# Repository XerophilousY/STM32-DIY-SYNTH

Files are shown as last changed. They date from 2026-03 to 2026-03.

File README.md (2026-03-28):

基于STM32F103C8T6温湿度计
---
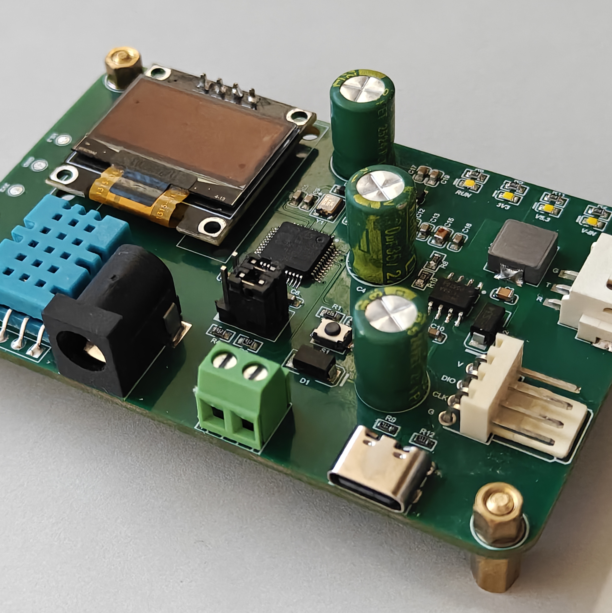
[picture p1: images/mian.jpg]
mian


系统提供多种电源输入方式，包括 Type-C 接口、3.81 mm 间距接线端子以及 DC005（5.5 mm × 2.5 mm）电源插座，以适应不同应用场景的供电需求。外部输入电压为 DC 12V。

电源管理部分采用分级降压方案：首先通过 TPS530 开关型 DC-DC 降压转换器（非线性）将输入电压降至 5V；随后由 TPS73033 或 RT9013 低压差线性稳压器（LDO）进一步稳压至 3.3V，为系统主控 MCU 及相关外设（包括传感器模块与 OLED 显示模块）提供稳定可靠的工作电源。

此外，系统设计预留标准下载接口及串口通信接口，可用于固件烧录、在线调试及数据通信，提升系统开发与维护的便利性。

1.***硬件组件***

主控：STM32F103C8T6 主频8MhZ

传感器：DHT11 单总线通信

显示方式：0.96寸OLED IIC通信

2.***开发工具***

Keil MDK 

Altium designer2020

3.***PCB版本迭代记录***

V0.0：采用的正反面设计，正面芯片，反面OLED,设计不美观，VSS和VDD连接相反

V1.0:晶振网络未连接到3.3v网络上，晶振不启振，打印出的时钟频率不对，软件倍频不生效

V2.0：使用AMS1117降压，输入12V降压至3.3V,压降太高，发热严重，电压不稳定，导致STM32死机，需要手动复位，在软件中加入看门狗后导致间隔性重启

V3.0:采用TPS5430降压至5V，后进入TPS73033降压至3.3v,没有5V输出，也没有3.3v,排查发现TPS73033输入和输出网络不一样，*导致无法形成回路*，因此没有3.3v输出

V4.0：采用四层板子设计，TPS5430用平面分割，但走线凌乱

V5.0：更改部分原件封装，删除0欧电阻作为隔离，每个部分的电源形成了回路，电源稳定

V6.0：锂电池供电版本,未单独区分

V7.0：当前版本

开发与贡献
--
该版本还有很多问题，如未大面积铺铜、集成度不高、欢迎通过以下方式参与贡献

-优化布局、走线

-优化选型，使其体积更轻盈小巧

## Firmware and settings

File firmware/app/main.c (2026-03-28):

//////////////////////////////////////////////////////////////////////////////////
//本程序只供学习使用，未经作者许可，不得用于其它任何用途
//
//  文 件 名   : main.c
//  版 本 号   : v2.0
//  作    者   : YANG HAO JI
//  生成日期   : 2018-10-31
//  最近修改   :
//  功能描述   : OLED I2C接口演示例程(STM32F103系列)
//              说明:
//              ----------------------------------------------------------------
//              GND  电源地
//              VCC  3.3v电源
//              D0   PA0（SCL）
//              D1   PA1（SDA）
//              RES  PA2（SPI模块改成IIC模块需要接此引脚，IIC模块用户请忽略）
//              ----------------------------------------------------------------
// 修改历史   :
// 日    期   :
// 修改内容   : 创建文件
//版权所有，盗版必究。
//All rights reserved
//******************************************************************************/
#include "board.h"
#include "sys.h"
#include "oled.h"
#include "bmp.h"
#include "dht11.h"
#include "stdio.h"
#include "bsp_uart.h"
#include "led.h"
#include "iwdg.h"

int main(void)
{
  DHT11_GPIO_Init();
  board_init();
  OLED_Init();
	LED_Init();
  OLED_ColorTurn(0);//0正常显示，1 反色显示
  OLED_DisplayTurn(0);//0正常显示 1 屏幕翻转显示
  uart1_init(115200U);

	
		IWDG_Feed();//喂狗
		Flag_IWDG_Feed=0;//停止喂狗，准备复位
  while(1)
    {
		
      OLED_Refresh();
      DHT11_Read_Data();

	                 	//表头
						OLED_ShowChinese(0, 0, 0, 16, 1);							   //温
						OLED_ShowChinese(25, 0, 1, 16, 1);							 //湿
						OLED_ShowChinese(50, 0, 2, 16, 1);							 //度
						OLED_ShowChinese(75, 0, 3, 16, 1);							 //检
						OLED_ShowChinese(100, 0, 4, 16, 1);							 //测
			
			
			
			OLED_ShowChinese(0, 25, 0, 16, 1);							 //温
      OLED_ShowChinese(25, 25, 2, 16, 1);							//度
			OLED_ShowString(50,25,":",16,1);
			
      OLED_ShowNum(65, 25, Get_temperature(), 2, 16, 0);      //获取温度值
			OLED_ShowChinese(85,25,5,16,1);												 //温度单位
			
			
			
			
			
			OLED_ShowChinese(0, 45, 1, 16, 1);							//湿
    	OLED_ShowChinese(25, 45, 2, 16, 1);				     //度
			OLED_ShowString(50,45,":",16,1);
			
      OLED_ShowNum(65, 45, Get_humidity(), 2, 16, 0);      //获取湿度值
			OLED_ShowString(90,45,"%",16,1);								   //湿度单位
			
			
			LED_RUN=LED_ON;
      delay_ms(500);
		
		LED_RUN=LED_OFF;
     

    }
}

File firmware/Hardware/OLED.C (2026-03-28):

#include "oled.h"
#include "stdlib.h"
#include "OLED_Font.h"
#include "board.h"

u8 OLED_GRAM[144][8];

//反显函数
void OLED_ColorTurn(u8 i)
{
	if(i==0)
		{
			OLED_WR_Byte(0xA6,OLED_CMD);//正常显示
		}
	if(i==1)
		{
			OLED_WR_Byte(0xA7,OLED_CMD);//反色显示
		}
}

//屏幕旋转180度
void OLED_DisplayTurn(u8 i)
{
	if(i==0)
		{
			OLED_WR_Byte(0xC8,OLED_CMD);//正常显示
			OLED_WR_Byte(0xA1,OLED_CMD);
		}
	if(i==1)
		{
			OLED_WR_Byte(0xC0,OLED_CMD);//反转显示
			OLED_WR_Byte(0xA0,OLED_CMD);
		}
}

//延时
void IIC_delay(void)
{
	u8 t=3;
	while(t--);
}

//起始信号
void I2C_Start(void)
{
	OLED_SDA_Set();
	OLED_SCL_Set();
	IIC_delay();
	OLED_SDA_Clr();
	IIC_delay();
	OLED_SCL_Clr();
	IIC_delay();
}

//结束信号
void I2C_Stop(void)
{
	OLED_SDA_Clr();
	OLED_SCL_Set();
	IIC_delay();
	OLED_SDA_Set();
}

//等待信号响应
void I2C_WaitAck(void) //测数据信号的电平
{
	OLED_SDA_Set();
	IIC_delay();
	OLED_SCL_Set();
	IIC_delay();
	OLED_SCL_Clr();
	IIC_delay();
}

//写入一个字节
void Send_Byte(u8 dat)
{
	u8 i;
	for(i=0;i<8;i++)
	{
		if(dat&0x80)//将dat的8位从最高位依次写入
		{
			OLED_SDA_Set();
    }
		else
		{
			OLED_SDA_Clr();
    }
		IIC_delay();
		OLED_SCL_Set();
		IIC_delay();
		OLED_SCL_Clr();//将时钟信号设置为低电平
		dat<<=1;
  }
}

//发送一个字节
//mode:数据/命令标志 0,表示命令;1,表示数据;
void OLED_WR_Byte(u8 dat,u8 mode)
{
	I2C_Start();
	Send_Byte(0x78);
	I2C_WaitAck();
	if(mode){Send_Byte(0x40);}
  else{Send_Byte(0x00);}
	I2C_WaitAck();
	Send_Byte(dat);
	I2C_WaitAck();
	I2C_Stop();
}

//开启OLED显示 
void OLED_DisPlay_On(void)
{
	OLED_WR_Byte(0x8D,OLED_CMD);//电荷泵使能
	OLED_WR_Byte(0x14,OLED_CMD);//开启电荷泵
	OLED_WR_Byte(0xAF,OLED_CMD);//点亮屏幕
}

//关闭OLED显示 
void OLED_DisPlay_Off(void)
{
	OLED_WR_Byte(0x8D,OLED_CMD);//电荷泵使能
	OLED_WR_Byte(0x10,OLED_CMD);//关闭电荷泵
	OLED_WR_Byte(0xAE,OLED_CMD);//关闭屏幕
}

//更新显存到OLED	
void OLED_Refresh(void)
{
	u8 i,n;
	for(i=0;i<8;i++)
	{
		OLED_WR_Byte(0xb0+i,OLED_CMD); //设置行起始地址
		OLED_WR_Byte(0x00,OLED_CMD);   //设置低列起始地址
		OLED_WR_Byte(0x10,OLED_CMD);   //设置高列起始地址
		I2C_Start();
		Send_Byte(0x78);
		I2C_WaitAck();
		Send_Byte(0x40);
		I2C_WaitAck();
		for(n=0;n<128;n++)
		{
			Send_Byte(OLED_GRAM[n][i]);
			I2C_WaitAck();
		}
		I2C_Stop();
  }
}
//清屏函数
void OLED_Clear(void)
{
	u8 i,n;
	for(i=0;i<8;i++)
	{
	   for(n=0;n<128;n++)
			{
			 OLED_GRAM[n][i]=0;//清除所有数据
			}
  }
	OLED_Refresh();//更新显示
}

//画点 
//x:0~127
//y:0~63
//t:1 填充 0,清空	
void OLED_DrawPoint(u8 x,u8 y,u8 t)
{
	u8 i,m,n;
	i=y/8;
	m=y%8;
	n=1<<m;
	if(t){OLED_GRAM[x][i]|=n;}
	else
	{
		OLED_GRAM[x][i]=~OLED_GRAM[x][i];
		OLED_GRAM[x][i]|=n;
		OLED_GRAM[x][i]=~OLED_GRAM[x][i];
	}
}

//画线
//x1,y1:起点坐标
//x2,y2:结束坐标
void OLED_DrawLine(u8 x1,u8 y1,u8 x2,u8 y2,u8 mode)
{
	u16 t; 
	int xerr=0,yerr=0,delta_x,delta_y,distance;
	int incx,incy,uRow,uCol;
	delta_x=x2-x1; //计算坐标增量 
	delta_y=y2-y1;
	uRow=x1;//画线起点坐标
	uCol=y1;
	if(delta_x>0)incx=1; //设置单步方向 
	else if (delta_x==0)incx=0;//垂直线 
	else {incx=-1;delta_x=-delta_x;}
	if(delta_y>0)incy=1;
	else if (delta_y==0)incy=0;//水平线 
	else {incy=-1;delta_y=-delta_x;}
	if(delta_x>delta_y)distance=delta_x; //选取基本增量坐标轴 
	else distance=delta_y;
	for(t=0;t<distance+1;t++)
	{
		OLED_DrawPoint(uRow,uCol,mode);//画点
		xerr+=delta_x;
		yerr+=delta_y;
		if(xerr>distance)
		{
			xerr-=distance;
			uRow+=incx;
		}
		if(yerr>distance)
		{
			yerr-=distance;
			uCol+=incy;
		}
	}
}
//x,y:圆心坐标
//r:圆的半径
void OLED_DrawCircle(u8 x,u8 y,u8 r)
{
	int a, b,num;
    a = 0;
    b = r;
    while(2 * b * b >= r * r)      
    {
        OLED_DrawPoint(x + a, y - b,1);
        OLED_DrawPoint(x - a, y - b,1);
        OLED_DrawPoint(x - a, y + b,1);
        OLED_DrawPoint(x + a, y + b,1);
 
        OLED_DrawPoint(x + b, y + a,1);
        OLED_DrawPoint(x + b, y - a,1);
        OLED_DrawPoint(x - b, y - a,1);
        OLED_DrawPoint(x - b, y + a,1);
        
        a++;
        num = (a * a + b * b) - r*r;//计算画的点离圆心的距离
        if(num > 0)
        {
            b--;
            a--;
        }
    }
}



//在指定位置显示一个字符,包括部分字符
//x:0~127
//y:0~63
//size1:选择字体 6x8/6x12/8x16/12x24
//mode:0,反色显示;1,正常显示
void OLED_ShowChar(u8 x,u8 y,u8 chr,u8 size1,u8 mode)
{
	u8 i,m,temp,size2,chr1;
	u8 x0=x,y0=y;
	if(size1==8)size2=6;
	else size2=(size1/8+((size1%8)?1:0))*(size1/2);  //得到字体一个字符对应点阵集所占的字节数
	chr1=chr-' ';  //计算偏移后的值
	for(i=0;i<size2;i++)
	{
		if(size1==8)
			  {temp=asc2_0806[chr1][i];} //调用0806字体
		else if(size1==12)
        {temp=asc2_1206[chr1][i];} //调用1206字体
		else if(size1==16)
        {temp=asc2_1608[chr1][i];} //调用1608字体
		else if(size1==24)
        {temp=asc2_2412[chr1][i];} //调用2412字体
		else return;
		for(m=0;m<8;m++)
		{
			if(temp&0x01)OLED_DrawPoint(x,y,mode);
			else OLED_DrawPoint(x,y,!mode);
			temp>>=1;
			y++;
		}
		x++;
		if((size1!=8)&&((x-x0)==size1/2))
		{x=x0;y0=y0+8;}
		y=y0;
  }
}


//显示字符串
//x,y:起点坐标  
//size1:字体大小 
//*chr:字符串起始地址 
//mode:0,反色显示;1,正常显示
void OLED_ShowString(u8 x,u8 y,u8 *chr,u8 size1,u8 mode)
{
	while((*chr>=' ')&&(*chr<='~'))//判断是不是非法字符!
	{
		OLED_ShowChar(x,y,*chr,size1,mode);
		if(size1==8)x+=6;
		else x+=size1/2;
		chr++;
  }
}

//m^n
u32 OLED_Pow(u8 m,u8 n)
{
	u32 result=1;
	while(n--)
	{
	  result*=m;
	}
	return result;
}

//显示数字
//x,y :起点坐标
//num :要显示的数字
//len :数字的位数
//size:字体大小
//mode:0,反色显示;1,正常显示
void OLED_ShowNum(u8 x,u8 y,u32 num,u8 len,u8 size1,u8 mode)
{
	u8 t,temp,m=0;
	if(size1==8)m=2;
	for(t=0;t<len;t++)
	{
		temp=(num/OLED_Pow(10,len-t-1))%10;
			if(temp==0)
			{
				OLED_ShowChar(x+(size1/2+m)*t,y,'0',size1,mode);
      }
			else 
			{
			  OLED_ShowChar(x+(size1/2+m)*t,y,temp+'0',size1,mode);
			}
  }
}

//显示汉字
//x,y:起点坐标
//num:汉字对应的序号
//mode:0,反色显示;1,正常显示
void OLED_ShowChinese(u8 x,u8 y,u8 num,u8 size1,u8 mode)
{
	u8 m,temp;
	u8 x0=x,y0=y;
	u16 i,size3=(size1/8+((size1%8)?1:0))*size1;  //得到字体一个字符对应点阵集所占的字节数
	for(i=0;i<size3;i++)
	{
		if(size1==16)
				{temp=Hzk1[num][i];}//调用16*16字体
		else if(size1==24)
				{temp=Hzk2[num][i];}//调用24*24字体
		else if(size1==32)       
				{temp=Hzk3[num][i];}//调用32*32字体
		else if(size1==64)
				{temp=Hzk4[num][i];}//调用64*64字体
		else return;
		for(m=0;m<8;m++)
		{
			if(temp&0x01)OLED_DrawPoint(x,y,mode);
			else OLED_DrawPoint(x,y,!mode);
			temp>>=1;
			y++;
		}
		x++;
		if((x-x0)==size1)
		{x=x0;y0=y0+8;}
		y=y0;
	}
}

//num 显示汉字的个数
//space 每一遍显示的间隔
//mode:0,反色显示;1,正常显示
void OLED_ScrollDisplay(u8 num,u8 space,u8 mode)
{
	u8 i,n,t=0,m=0,r;
	while(1)
	{
		if(m==0)
		{
	    OLED_ShowChinese(128,24,t,16,mode); //写入一个汉字保存在OLED_GRAM[][]数组中
			t++;
		}
		if(t==num)
			{
				for(r=0;r<16*space;r++)      //显示间隔
				 {
					for(i=1;i<144;i++)
						{
							for(n=0;n<8;n++)
							{
								OLED_GRAM[i-1][n]=OLED_GRAM[i][n];
							}
						}
           OLED_Refresh();
				 }
        t=0;
      }
		m++;
		if(m==16){m=0;}
		for(i=1;i<144;i++)   //实现左移
		{
			for(n=0;n<8;n++)
			{
				OLED_GRAM[i-1][n]=OLED_GRAM[i][n];
			}
		}
		OLED_Refresh();
	}
}
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

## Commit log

2026-03-28 Create pcb
2026-03-28 Rename pcb to PCB Project
2026-03-28 Rename PCB Project to PCB Doc
2026-03-28 Create PCB doc
2026-03-28 Rename DHT11V7.0.PcbDoc to pcb doc/DHT11V7.0.PcbDoc
    [DHT11V7.0.PcbDoc]
2026-03-28 Rename DHT11V7.0.PrjPCB to pcb doc/DHT11V7.0.PrjPCB
    [DHT11V7.0.PrjPCB]
2026-03-28 Rename DHT11V7.0.SchDoc to pcb doc/DHT11V7.0.SchDoc
    [DHT11V7.0.SchDoc]
2026-03-28 整理项目结构
    PCB设计文档放在pcb doc
    源代码放在firmware
